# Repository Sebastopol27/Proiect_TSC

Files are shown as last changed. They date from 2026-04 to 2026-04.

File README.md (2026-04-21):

## 1. Diagrama Bloc a Sistemului
Arhitectura hardware este centrata pe microcontrolerul nRF52840, gestionand distributia puterii, comunicatia cu senzorii si interfata vizuala.

      +----------+          +-----------+          +----------+
      |  USB 5V  | -------->|  BQ25180  | -------->|  RT6160  |
      +----------+          | (Charger) |          | (Reg)    |
                            +-----------+          +----------+
                                  ^                     |
                                  |                     | (3.3V Rail)
                                  v                     v
      +----------+          +-----------+          +----------+
      |   LiPo   | <------> |  BAT Node |          | nRF52840 |
      | Battery  |          +-----------+          |  (MCU)   |
      +----------+                |                +----------+
                                  v                     |
                            +-----------+               |
                            | MAX17048  | <-------------+ (I2C Bus)
                            | (Fuel G.) |               |
                            +-----------+               |
                                                        |
         +----------------------------------------------+
         |               |               |              |
         v (I2C)         v (I2C)         v (SPI)        v (GPIO)
   +-----------+   +-----------+   +-----------+   +------------+
   |  BMA421   |   | DRV2605L  |   |  E-Paper  |   | 3x Buttons |
   |  (Accel)  |   | (Haptic)  |   |  Display  |   +------------+
   +-----------+   +-----------+   +-----------+
                         |               ^
                         v               | (Power Gate)
                   +-----------+   +-----------+
                   |Vibe Motor |   | SI2301CDS |
                   +-----------+   |  (PFET)   |
                                   +-----------+

## 2. Bill of Materials (BOM)
Componentele sunt selectate pentru catalogul de asamblare JLCPCB.

| Functie | Componenta | Capsula |
|---|---|---|
| MCU | nRF52840-QIAA  | aQFN73 | 
| Charger | BQ25180YBGR | DSBGA-8 |
| Regulator | RT6160AWSC | WLCSP-15 |
| Fuel Gauge | MAX17048G+T10  | DFN-8 |
| Accel | BMA421 | LGA-12 |
| Haptic Drv | DRV2605LDGSR | VSSOP-10 |
| Vibe Motor | LCM1027B3605F  | Wire |
| EPD PFET | SI2301CDS | SOT-23 |

## 3. Functionalitate Hardware in Detaliu

### Managementul Puterii (Power Tree)
[cite_start]Sistemul utilizeaza o arhitectura tip "power-path":
* **BQ25180**: Gestioneaza incarcarea bateriei LiPo de 250 mAh si asigura tranzitia automata intre alimentarea USB si baterie.
* **RT6160**: Regulator buck-boost setat pentru o iesire de 3.3V (VSEL low), asigurand stabilitatea MCU-ului pe toata durata de descarcare a bateriei.
* **MAX17048**: Monitorizeaza precis tensiunea bateriei si starea de incarcare (SOC) prin masurare directa pe VBAT.

### Senzori si Interfete
* **Magistrala I2C**: Partajata intre accelerometru, fuel gauge, charger, regulator si driverul haptic.
* **Interfata SPI**: Utilizata exclusiv pentru controller-ul ecranului e-paper.
* **BMA421**: Detecteaza pașii mereu activ si trimite intreruperi hardware (INT1) catre MCU pentru wake-up.
* **Haptics**: Driverul DRV2605L controleaza motorul ERM pentru alerte tactile, fiind activat (EN) doar in timpul utilizarii pentru a economisi energie.

### Calcule si Eficienta Consumului
* **Power Gating**: Un PFET (SI2301) controlat de MCU (P1.01) intrerupe alimentarea ecranului e-paper (VEPD) cand acesta nu se afla intr-un ciclu de refresh.
* **Tinta Autonomie**: >= 30 de zile cu refresh de ecran o data pe minut si maxim 50 de notificari zilnice.

## 4. Alocarea Pinilor nRF52840

Pinii au fost selectati pentru a optimiza rutarea pe un PCB cu 4 straturi.

| Componenta | Pin MCU | Justificare / Functie |
|---|---|---|
| **I2C SDA** | P0.06  | Comunicatie date senzori si IC-uri power. |
| **I2C SCL** | P0.07 | Ceas magistrala I2C (10k pull-up extern). |
| **SPI SCK** | P0.02 | Ceas SPI pentru transfer rapid display. |
| **SPI MOSI** | P0.03 | Date seriale catre ecran e-paper. |
| **SPI CS** | P0.05 | Selectie chip afisaj (Chip Select). |
| **EPD DC** | P0.15 | Selectie Data/Command pentru display. |
| **EPD RST** | P0.16 | Reset hardware display. |
| **EPD Busy** | P0.17 | Monitorizare stare procesare refresh ecran. |
| **EPD Power** | P1.01 | Poarta PFET pentru management alimentare VEPD. |
| **Accel INT** | P0.08 | INT1 (wake primar pentru pedometru). |
| **Accel INT2** | P1.08 | INT2 pentru evenimente secundare. |
| **Fuel Gauge** | P0.10 | ALRT pentru prag baterie descarcata. |
| **Charger INT** | P0.11 | Intrerupere pentru evenimente de incarcare. |
| **Haptic EN** | P0.12 | Enable pentru oprirea driverului haptic. |
| **Buttons** | P0.13, P0.14 | Up si Down (active low, wake source). |
| **Button Ent** | P1.00 | Enter / Esc (active low). |

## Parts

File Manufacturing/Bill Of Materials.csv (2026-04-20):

Reference Designators | Quantity | Description | Package | Value | Manufacturer | Manufacturer Part Number | Vendor | Vendor Part Number | Top/Bottom
 | 1 | PCB Board | Board
ANT1 | 1 | Antennas 2.45GHz ANTENNA | 2450AT18B100E_ANTC3216X140N | 2450AT18B100E_2450AT18B100E |  |  |  |  | Top
C1, C2, C17, C18 | 4 | Generic chip capacitor | NORDIC_NRF_3_RESC0201_L | 12p |  |  |  |  | Top
C1-EP-DR, C24, C39 | 3 | 0402 (1005 Metric) | PERFECT_0402_0402 | 10u |  |  |  |  | Top
C2-EP-DR | 1 | Generic chip capacitor | NORDIC_NRF_3_RESC0603_L | 4.7u/25V |  |  |  |  | Top
C3, C4 | 2 | Generic chip capacitor | NORDIC_NRF_3_RESC0201_L | 1p |  |  |  |  | Top
C5, C7, C8, C12, C19 | 5 | Generic chip capacitor | NORDIC_NRF_3_RESC0201_L | 100n |  |  |  |  | Top
C6, C14, C20, C21, C43 | 5 | 0402 (1005 Metric) | PERFECT_0402_0402 | 4.7u |  |  |  |  | Top
C9 | 1 | Generic chip capacitor | NORDIC_NRF_3_RESC0201_L | 820p (N.C.) |  |  |  |  | Top
C10, C22 | 2 | Generic chip capacitor | NORDIC_NRF_3_RESC0201_L | N.C. |  |  |  |  | Top
C11 | 1 | Generic chip capacitor | NORDIC_NRF_3_RESC0201_L | 100p |  |  |  |  | Top
C13 | 1 | 0402 (1005 Metric) | PERFECT_0402_0402 | N.C. |  |  |  |  | Top
C15, C29, C30, C31, C32, C37, C38 | 7 | 0402 (1005 Metric) | PERFECT_0402_0402 | 1u |  |  |  |  | Top
C16 | 1 | Generic chip capacitor | NORDIC_NRF_3_RESC0201_L | 47n |  |  |  |  | Top
C23, C27, C34, C42 | 4 | Generic chip capacitor | NORDIC_NRF_3_RESC0201_L | 0.1u |  |  |  |  | Top
C25 | 1 | Generic chip capacitor | NORDIC_NRF_3_RESC0201_L | 22u |  |  |  |  | Top
C33 | 1 | 0402 (1005 Metric) | PERFECT_0402_0402 | 22u |  |  |  |  | Top
D2, D4, D5 | 3 | ON SEMICONDUCTOR - MBR0530 - DIODE, SCHOTTKY, 0.5A, 30V, SOD-123 | SOD3716X135N | MBR0530 |  |  |  |  | Top
D3\ | 1 | Low Cap. ESD Protection Auto SOT-23-6 STMicroelectronics USBLC6-2SC6Y, Dual Uni-Directional TVS Diode Array, 6-Pin SOT-23 | SOT95P280X145-6N | ESP32_C6_LIBRARY_3_USBLC6-2SC6Y |  |  |  |  | Top
EPD_C1, EPD_C2, EPD_C6, EPD_C7, EPD_C8, EPD_C9, EPD_C10, EPD_C11, EPD_C12 | 9 | Generic chip capacitor | NORDIC_NRF_3_RESC0603_L | 1u/50V |  |  |  |  | Top
EPD_C5 | 1 | Generic chip capacitor | NORDIC_NRF_3_RESC0603_L | 0.1u/50V |  |  |  |  | Top
IC1 | 1 | Charger IC Lithium Ion/Polymer, Lithium Iron Phosphate 8-DSBGA (1.6x1.1) | BQ25180YBGR_BGA8C40P2X4_100X155X50 | BQ25180YBGR_BQ25180YBGR |  |  |  |  | Top
IC2 | 1 | Haptic Driver for ERM/LRA with Built-In Library and Smart Loop Architecture | DRV2605YZFR_BGA9C50P3X3_144X144X62 | DRV2605YZFR |  |  |  |  | Top
IC3 | 1 | Accelerometers Triaxial low-g 12bit Acceleration Sensor | BMA423_BMA423 | BMA423_BMA423 |  |  |  |  | Top
IC9 | 1 | Buck-Boost Regulator Positive Output Step-Up/Step-Down I2C DC-DC Controller IC 15-WL-CSP (BSC) (1.4x2.3) | RT6160AWSC_BGA15C40P3X5_140X230X60 | RT6160AWSC_RT6160AWSC |  |  |  |  | Top
J1 | 1 | FFC & FPC Connectors 0.5mm FPC RA SMT Dual Contact 24Ckt | 503480-2400_5034802400 | 503480-2400_503480-2400 |  |  |  |  | Top
J2 | 1 | CABLE ADAPTER 6 POS | TC2030-IDC_TC2030IDC | TC2030-IDC_TC2030-IDC |  |  |  |  | Top
J4 | 1 | Check availability | KINGHELM_KH-TYPE-C-16P | KH-TYPE-C-16P_KH-TYPE-C-16P |  |  |  |  | Top
L1 | 1 | Generic chip inductor | NORDIC_NRF_2_RESC0201_L | 3.9n |  |  |  |  | Top
L2 | 1 | Generic chip inductor | NORDIC_NRF_2_RESC0402_L | 10u |  |  |  |  | Top
L3 | 1 | Generic chip inductor | NORDIC_NRF_2_RESC0201_L | 15n |  |  |  |  | Top
L5 | 1 |  | ESP32_C6_LIBRARY_2_IND_4828-WE-TPC_WRE | 68u |  |  |  |  | Top
L7 | 1 | SMD / SMT Inductors (Coils), L=0.47?H, L x W x T : | MLP2016SR47MT0S1_INDC2016X100N | FTC252012SR47MBCA |  |  |  |  | Top
Q1 | 1 | P-channel MOSFETs | ESP32_WROVER_SPARKFUN-DISCRETESEMI_SOT23-3 | 20V/4.2A/52mΩ/1.4W |  |  |  |  | Top
Q3 | 1 | MOSFET N-Ch 30V 1.5A TrenchFET SC70 Vishay Si1308EDL-T1-GE3 N-channel MOSFET Transistor, 1.5 A, 30 V, 3-Pin SC-70 | SOT65P210X110-3N | ESP32_C6_LIBRARY_6_SI1308EDL-T1-GE3 |  |  |  |  | Top
R_PWR_EPD, R2_EP_DR, R5, R7, R8 | 5 | 7.68k 0201 Thin Film Surface Mount Fixed Resistor +/-0.5% 0.031W CPF0201D7K68C1 | CPF0201D7K68C1_0201 | 10K |  |  |  |  | Top
R1_EP_DR | 1 | 7.68k 0201 Thin Film Surface Mount Fixed Resistor +/-0.5% 0.031W CPF0201D7K68C1 | CPF0201D7K68C1_0201 | 0.47 |  |  |  |  | Top
R1_TYPE_SEL | 1 | 7.68k 0201 Thin Film Surface Mount Fixed Resistor +/-0.5% 0.031W CPF0201D7K68C1 | CPF0201D7K68C1_0201 | 2.2 |  |  |  |  | Top
R1_USB, R2_USB | 2 | 7.68k 0201 Thin Film Surface Mount Fixed Resistor +/-0.5% 0.031W CPF0201D7K68C1 | CPF0201D7K68C1_0201 | 5K1 |  |  |  |  | Top
R2, R3, R4 | 3 | 7.68k 0201 Thin Film Surface Mount Fixed Resistor +/-0.5% 0.031W CPF0201D7K68C1 | CPF0201D7K68C1_0201 | 0 |  |  |  |  | Top
R9 | 1 | 7.68k 0201 Thin Film Surface Mount Fixed Resistor +/-0.5% 0.031W CPF0201D7K68C1 | CPF0201D7K68C1_0201 | 10k |  |  |  |  | Top
R17, R18 | 2 | 7.68k 0201 Thin Film Surface Mount Fixed Resistor +/-0.5% 0.031W CPF0201D7K68C1 | CPF0201D7K68C1_0201 | 3K3 |  |  |  |  | Top
SJ1 | 1 | SMD solder JUMPER | JUMPER_SJ |  |  |  |  |  | Top
SW_DN, SW_ENT, SW_UP | 3 |  | SW_EVP-AKE31A_PAN | 2025-10-22_07-23-44_LIBRARY_EVP-AKE31ASW_EVP-AKE31A_PAN |  |  |  |  | Top
TP_3.3V, TP_3V3, TP_BAT_GND, TP_GND, TP_ON, TP_OP, TP_RESET, TP_SCL, TP_SDA, TP_SWDCLK, TP_SWDIO, TP_SWO, TP_VBAT, TP_VREG | 14 | Test pad | HECTOR_WATCH_1_TP20R | HECTOR_WATCH_1_TPTP20R |  |  |  |  | Top
U$1 | 1 | nRF52840 | NORDIC_NRF_4_AQFN50P700X700X85_HS-74N | NORDIC_NRF_4_NRF52840_QF |  |  |  |  | Top
U3 | 1 | Check availability | SON50P200X200X80-9N | ESP32_C6_LIBRARY_MAX17048G+T10 |  |  |  |  | Top
X1 | 1 |  | NORDIC_NRF_BT-XTAL_2016_N | 32M |  |  |  |  | Top
X2 | 1 |  | NORDIC_NRF_1_XTAL_3215_N | 32.768k |  |  |  |  | Top

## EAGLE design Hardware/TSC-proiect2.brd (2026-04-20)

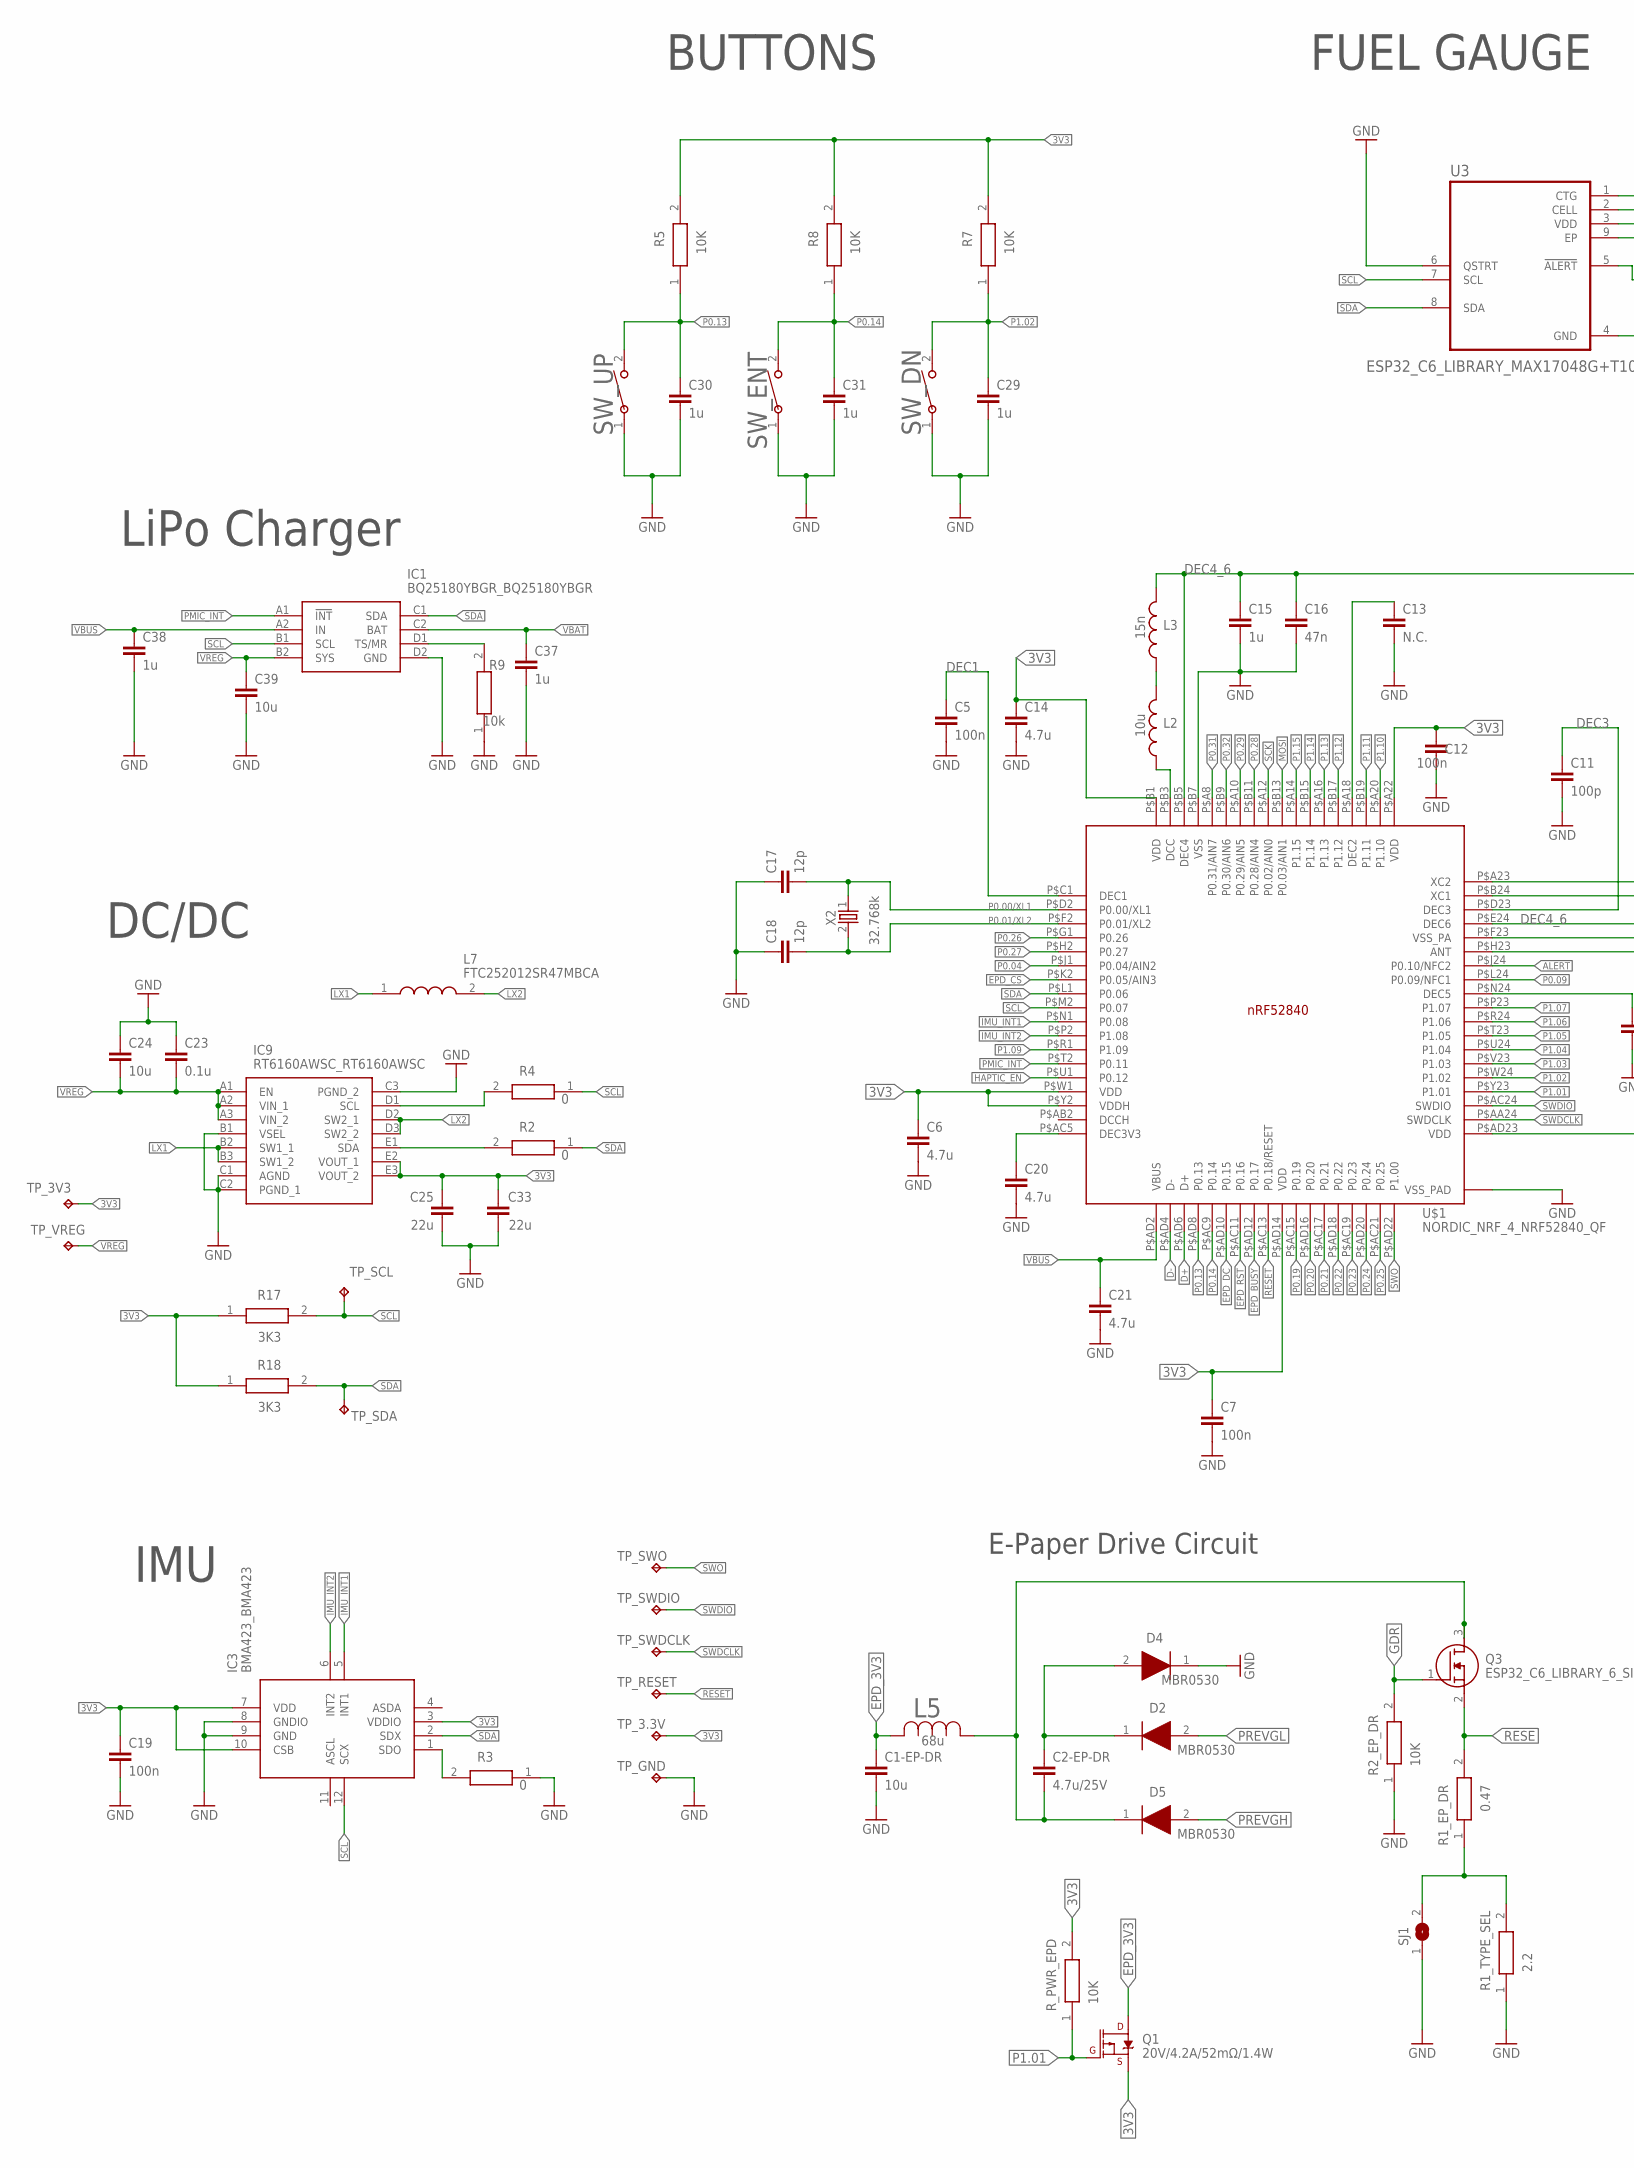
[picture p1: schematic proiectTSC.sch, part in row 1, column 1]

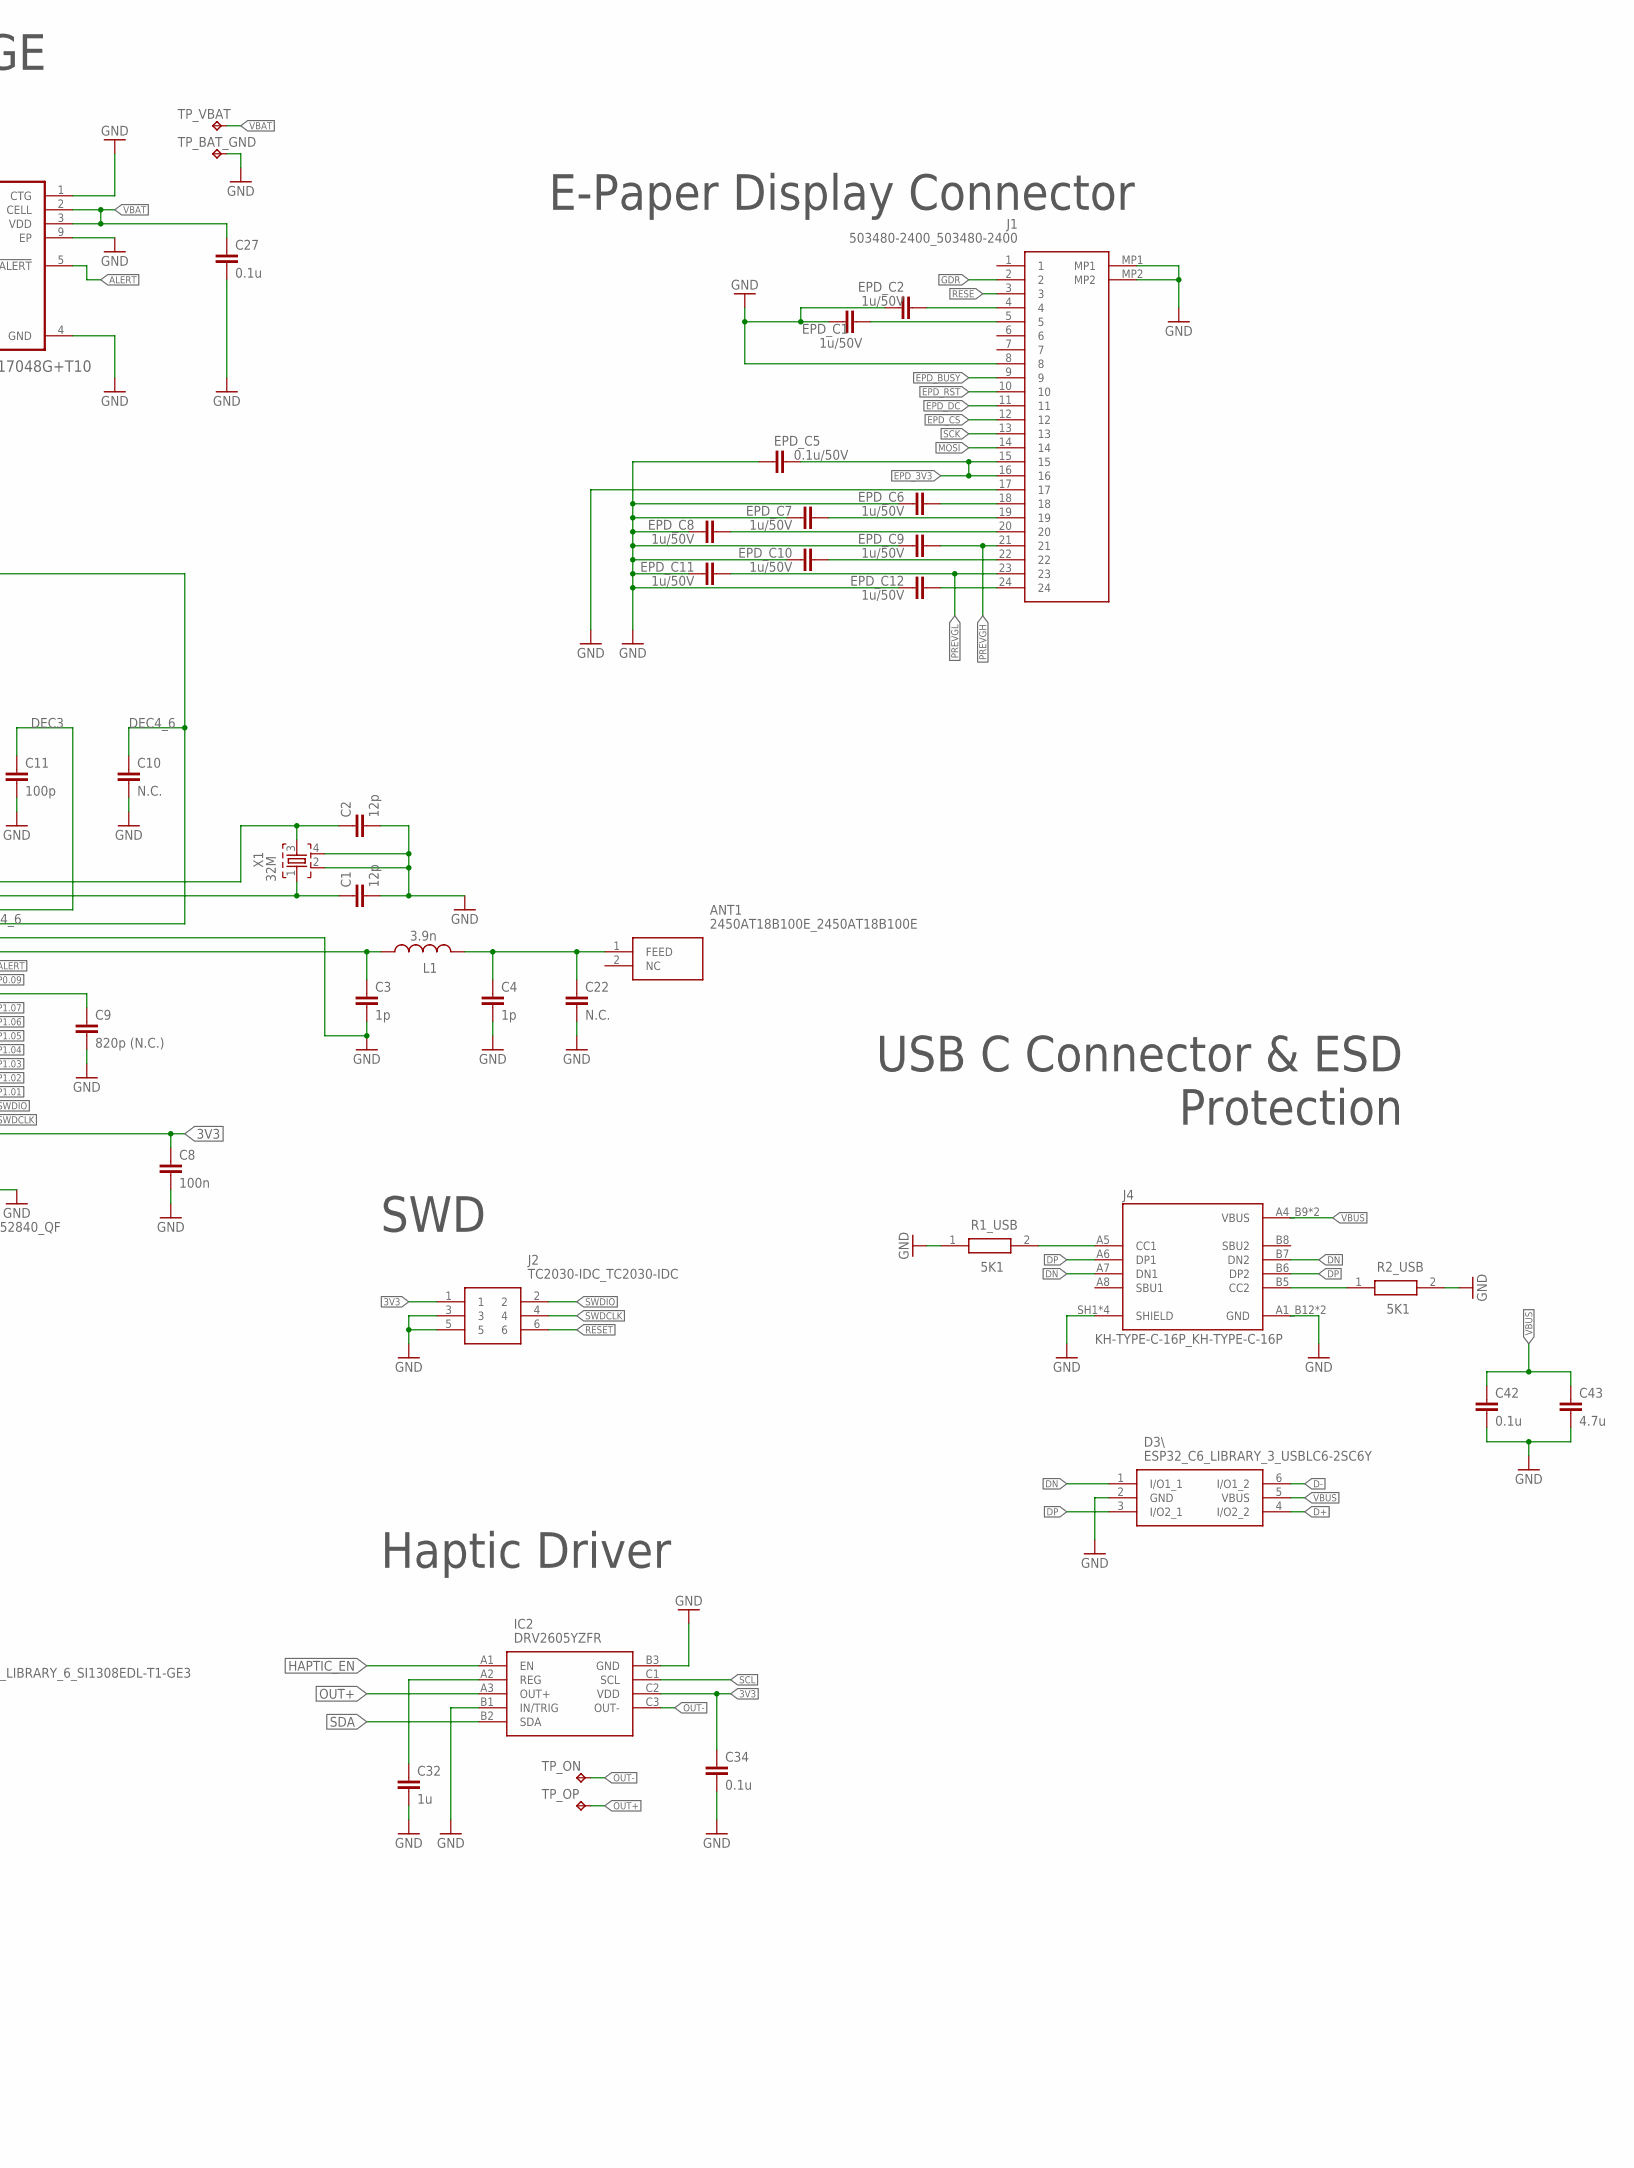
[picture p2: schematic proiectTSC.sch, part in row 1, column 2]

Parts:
ANT1: 2450AT18B100E_2450AT18B100E; 2450AT18B100E_ANTC3216X140N
C1, C2, C17, C18: 12p; NORDIC_NRF_3_RESC0201_L
C1-EP-DR, C24, C39: 10u; PERFECT_0402_0402
C2-EP-DR: 4.7u/25V; NORDIC_NRF_3_RESC0603_L
C3, C4: 1p; NORDIC_NRF_3_RESC0201_L
C5, C7, C8, C12, C19: 100n; NORDIC_NRF_3_RESC0201_L
C6, C14, C20, C21, C43: 4.7u; PERFECT_0402_0402
C9: 820p (N.C.); NORDIC_NRF_3_RESC0201_L
C10, C22: N.C.; NORDIC_NRF_3_RESC0201_L
C11: 100p; NORDIC_NRF_3_RESC0201_L
C13: N.C.; PERFECT_0402_0402
C15, C29, C30, C31, C32, C37, C38: 1u; PERFECT_0402_0402
C16: 47n; NORDIC_NRF_3_RESC0201_L
C23, C27, C34, C42: 0.1u; NORDIC_NRF_3_RESC0201_L
C25: 22u; NORDIC_NRF_3_RESC0201_L
C33: 22u; PERFECT_0402_0402
D2, D4, D5: MBR0530; ESP32_C6_LIBRARY_5_SOD3716X135N
D3\: ESP32_C6_LIBRARY_3_USBLC6-2SC6Y; ESP32_C6_LIBRARY_3_SOT95P280X145-6N
EPD_C1, EPD_C2, EPD_C6, EPD_C7, EPD_C8, EPD_C9, EPD_C10, EPD_C11, EPD_C12: 1u/50V; NORDIC_NRF_3_RESC0603_L
EPD_C5: 0.1u/50V; NORDIC_NRF_3_RESC0603_L
IC1: BQ25180YBGR_BQ25180YBGR; BQ25180YBGR_BGA8C40P2X4_100X155X50
IC2: DRV2605YZFR; DRV2605YZFR_BGA9C50P3X3_144X144X62
IC3: BMA423_BMA423
IC9: RT6160AWSC_RT6160AWSC; RT6160AWSC_BGA15C40P3X5_140X230X60
J1: 503480-2400_503480-2400; 503480-2400_5034802400
J2: TC2030-IDC_TC2030-IDC; TC2030-IDC_TC2030IDC
J4: KH-TYPE-C-16P_KH-TYPE-C-16P; KH-TYPE-C-16P_KINGHELM_KH-TYPE-C-16P
L1: 3.9n; NORDIC_NRF_2_RESC0201_L
L2: 10u; NORDIC_NRF_2_RESC0402_L
L3: 15n; NORDIC_NRF_2_RESC0201_L
L5: 68u; ESP32_C6_LIBRARY_2_IND_4828-WE-TPC_WRE
L7: FTC252012SR47MBCA; MLP2016SR47MT0S1_INDC2016X100N
Q1: 20V/4.2A/52mΩ/1.4W; ESP32_C6_LIBRARY_4_ESP32_C6_LIBRARY_4_ESP32_C6_LIBRARY_4_ES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
Q3: ESP32_C6_LIBRARY_6_SI1308EDL-T1-GE3; ESP32_C6_LIBRARY_6_SOT65P210X110-3N
R1_EP_DR: 0.47; CPF0201D7K68C1_0201
R1_TYPE_SEL: 2.2; CPF0201D7K68C1_0201
R1_USB, R2_USB: 5K1; CPF0201D7K68C1_0201
R2, R3, R4: 0; CPF0201D7K68C1_0201
R2_EP_DR, R5, R7, R8: 10K; CPF0201D7K68C1_0201
R9: 10k; CPF0201D7K68C1_0201
R17, R18: 3K3; CPF0201D7K68C1_0201
R_PWR_EPD: 10K; CPF0201D7K68C1_0201
SJ1: ESP32_C6_LIBRARY_7_JUMPER_SJ
SW_DN: 2025-10-22_07-23-44_LIBRARY_EVP-AKE31ASW_EVP-AKE3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; 2025-10-22_07-23-44_LIBRARY_SW_EVP-AKE31A_PAN
SW_ENT: 2025-10-22_07-23-44_LIBRARY_EVP-AKE31ASW_EVP-AKE3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; 2025-10-22_07-23-44_LIBRARY_SW_EVP-AKE31A_PAN
SW_UP: 2025-10-22_07-23-44_LIBRARY_EVP-AKE31ASW_EVP-AKE3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; 2025-10-22_07-23-44_LIBRARY_SW_EVP-AKE31A_PAN
TP_3.3V, TP_3V3: HECTOR_WATCH_1_TPTP20R; HECTOR_WATCH_1_TP20R
TP_BAT_GND: HECTOR_WATCH_1_TPTP20R; HECTOR_WATCH_1_TP20R
TP_GND: HECTOR_WATCH_1_TPTP20R; HECTOR_WATCH_1_TP20R
TP_ON: HECTOR_WATCH_1_TPTP20R; HECTOR_WATCH_1_TP20R
TP_OP: HECTOR_WATCH_1_TPTP20R; HECTOR_WATCH_1_TP20R
TP_RESET: HECTOR_WATCH_1_TPTP20R; HECTOR_WATCH_1_TP20R
TP_SCL: HECTOR_WATCH_1_TPTP20R; HECTOR_WATCH_1_TP20R
TP_SDA: HECTOR_WATCH_1_TPTP20R; HECTOR_WATCH_1_TP20R
TP_SWDCLK: HECTOR_WATCH_1_TPTP20R; HECTOR_WATCH_1_TP20R
TP_SWDIO: HECTOR_WATCH_1_TPTP20R; HECTOR_WATCH_1_TP20R
TP_SWO: HECTOR_WATCH_1_TPTP20R; HECTOR_WATCH_1_TP20R
TP_VBAT: HECTOR_WATCH_1_TPTP20R; HECTOR_WATCH_1_TP20R
TP_VREG: HECTOR_WATCH_1_TPTP20R; HECTOR_WATCH_1_TP20R
U3: ESP32_C6_LIBRARY_MAX17048G+T10; ESP32_C6_LIBRARY_SON50P200X200X80-9N
U$1: NORDIC_NRF_4_NRF52840_QF; NORDIC_NRF_4_AQFN50P700X700X85_HS-74N
X1: 32M; NORDIC_NRF_BT-XTAL_2016_N
X2: 32.768k; NORDIC_NRF_1_XTAL_3215_N

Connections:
3V3: C6.1, C7.1, C8.1, C12.1, C14.1, C19.1, C25.2, C33.2, C34.1, IC2.C2 (VDD), IC3.3 (VDDIO), IC3.7 (VDD), IC3.10 (CSB), IC9.E2 (VOUT_1), IC9.E3 (VOUT_2), J2.1, Q1.2 (S), R5.2, R7.2, R8.2, R_PWR_EPD.2, TP_3.3V.TP, TP_3V3.TP, U$1.P$A22 (VDD), U$1.P$AD14 (VDD), U$1.P$AD23 (VDD), U$1.P$B1 (VDD), U$1.P$W1 (VDD), U$1.P$Y2 (VDDH)
ALERT: U3.5 (!ALERT), U$1.P$J24 (P0.10/NFC2)
D+: D3\.4 (I/O2_2), U$1.P$AD6 (D+)
D-: D3\.6 (I/O1_2), U$1.P$AD4 (D-)
DEC1: C5.1, U$1.P$C1 (DEC1)
DEC3: C11.1, U$1.P$D23 (DEC3)
DEC4_6: C10.1, C15.1, C16.1, L3.2, U$1.P$B5 (DEC4), U$1.P$E24 (DEC6)
DN: D3\.1 (I/O1_1), J4.A7 (DN1), J4.B7 (DN2)
DP: D3\.3 (I/O2_1), J4.A6 (DP1), J4.B6 (DP2)
EPD_3V3: C1-EP-DR.1, EPD_C5.2, J1.15, J1.16, L5.2, Q1.3 (D)
EPD_BUSY: J1.9, U$1.P$AD12 (P0.17)
EPD_CS: J1.12, U$1.P$K2 (P0.05/AIN3)
EPD_DC: J1.11, U$1.P$AD10 (P0.15)
EPD_RST: J1.10, U$1.P$AC11 (P0.16)
GDR: J1.2, Q3.1 (G), R2_EP_DR.2
GND: C1.2, C1-EP-DR.2, C2.2, C3.2, C4.2, C5.2, C6.2, C7.2, C8.2, C9.2, C10.2, C11.2, C12.2, C13.2, C14.2, C15.2, C16.2, C17.1, C18.1, C19.2, C20.2, C21.2, C22.2, C23.1, C24.1, C25.1, C27.2, C29.2, C30.2, C31.2, C32.2, C33.1, C34.2, C37.2, C38.2, C39.2, C42.2, C43.2, D3\.2 (GND), D4.1 (K), EPD_C1.1, EPD_C2.1, EPD_C5.1, EPD_C6.1, EPD_C7.1, EPD_C8.1, EPD_C9.1, EPD_C10.1, EPD_C11.1, EPD_C12.1, IC1.D2 (GND), IC2.B1 (IN/TRIG), IC2.B3 (GND), IC3.8 (GNDIO), IC3.9 (GND), IC9.B1 (VSEL), IC9.C1 (AGND), IC9.C2 (PGND_1), IC9.C3 (PGND_2), J1.8, J1.17, J1.MP1, J1.MP2, J2.3, J2.5, J4.A1_B12 (GND), J4.A12_B1 (GND), J4.SH1 (SHIELD), J4.SH2 (SHIELD), J4.SH3 (SHIELD), J4.SH4 (SHIELD), R1_TYPE_SEL.1, R1_USB.1, R2_EP_DR.1, R2_USB.2, R3.1, R9.1, SJ1.1, SW_DN.1, SW_ENT.1, SW_UP.1, TP_BAT_GND.TP, TP_GND.TP, U3.1 (CTG), U3.4 (GND), U3.6 (QSTRT), U3.9 (EP), U$1.P$74 (VSS_PAD), U$1.P$75 (VSS_PAD), U$1.P$76 (VSS_PAD), U$1.P$77 (VSS_PAD), U$1.P$78 (VSS_PAD), U$1.P$79 (VSS_PAD), U$1.P$80 (VSS_PAD), U$1.P$81 (VSS_PAD), U$1.P$82 (VSS_PAD), U$1.P$83 (VSS_PAD), U$1.P$84 (VSS_PAD), U$1.P$85 (VSS_PAD), U$1.P$86 (VSS_PAD), U$1.P$87 (VSS_PAD), U$1.P$88 (VSS_PAD), U$1.P$89 (VSS_PAD), U$1.P$90 (VSS_PAD), U$1.P$B7 (VSS), U$1.P$F23 (VSS_PA), X1.2, X1.4
HAPTIC_EN: IC2.A1 (EN), U$1.P$U1 (P0.12)
IMU_INT1: IC3.5 (INT1), U$1.P$N1 (P0.08)
IMU_INT2: IC3.6 (INT2), U$1.P$P2 (P1.08)
LX1: IC9.B2 (SW1_1), IC9.B3 (SW1_2), L7.1
LX2: IC9.D2 (SW2_1), IC9.D3 (SW2_2), L7.2
MOSI: J1.14, U$1.P$B13 (P0.03/AIN1)
unnamed: L2.1, U$1.P$B3 (DCC)
unnamed: L2.2, L3.1
unnamed: C13.1, U$1.P$A18 (DEC2)
unnamed: C20.1, U$1.P$AC5 (DEC3V3)
unnamed: C9.1, U$1.P$N24 (DEC5)
unnamed: C3.1, L1.1, U$1.P$H23 (ANT)
unnamed: ANT1.1 (FEED), C4.1, C22.1, L1.2
unnamed: C1.1, U$1.P$B24 (XC1), X1.1
unnamed: C2.1, U$1.P$A23 (XC2), X1.3
unnamed: IC1.D1 (TS/MR), R9.2
unnamed: IC9.D1 (SCL), R4.2
unnamed: IC9.E1 (SDA), R2.2
unnamed: R17.1, R18.1
unnamed: R1_EP_DR.1, R1_TYPE_SEL.2, SJ1.2
unnamed: C32.1, IC2.A2 (REG)
unnamed: C2-EP-DR.1, D2.1 (K), D4.2 (A)
unnamed: C2-EP-DR.2, D5.1 (K), L5.1, Q3.3 (D)
unnamed: IC3.1 (SDO), R3.2
unnamed: EPD_C6.2, J1.18
unnamed: EPD_C7.2, J1.19
unnamed: EPD_C2.2, J1.4
unnamed: EPD_C1.2, J1.5
unnamed: EPD_C8.2, J1.20
unnamed: EPD_C10.2, J1.22
unnamed: EPD_C12.2, J1.24
unnamed: J4.B5 (CC2), R2_USB.1
unnamed: J4.A5 (CC1), R1_USB.2
OUT+: IC2.A3 (OUT+), TP_OP.TP
OUT-: IC2.C3 (OUT-), TP_ON.TP
P0.00/XL1: C17.2, U$1.P$D2 (P0.00/XL1), X2.1
P0.01/XL2: C18.2, U$1.P$F2 (P0.01/XL2), X2.2
P0.04: U$1.P$J1 (P0.04/AIN2)
P0.09: U$1.P$L24 (P0.09/NFC1)
P0.13: C30.1, R5.1, SW_UP.2, U$1.P$AD8 (P0.13)
P0.14: C31.1, R8.1, SW_ENT.2, U$1.P$AC9 (P0.14)
P0.19: U$1.P$AC15 (P0.19)
P0.20: U$1.P$AD16 (P0.20)
P0.21: U$1.P$AC17 (P0.21)
P0.22: U$1.P$AD18 (P0.22)
P0.23: U$1.P$AC19 (P0.23)
P0.24: U$1.P$AD20 (P0.24)
P0.25: U$1.P$AC21 (P0.25)
P0.26: U$1.P$G1 (P0.26)
P0.27: U$1.P$H2 (P0.27)
P0.28: U$1.P$B11 (P0.28/AIN4)
P0.29: U$1.P$A10 (P0.29/AIN5)
P0.31: U$1.P$A8 (P0.31/AIN7)
P0.32: U$1.P$B9 (P0.30/AIN6)
P1.01: Q1.1 (G), R_PWR_EPD.1, U$1.P$Y23 (P1.01)
P1.02: C29.1, R7.1, SW_DN.2, U$1.P$W24 (P1.02)
P1.03: U$1.P$V23 (P1.03)
P1.04: U$1.P$U24 (P1.04)
P1.05: U$1.P$T23 (P1.05)
P1.06: U$1.P$R24 (P1.06)
P1.07: U$1.P$P23 (P1.07)
P1.09: U$1.P$R1 (P1.09)
P1.10: U$1.P$A20 (P1.10)
P1.11: U$1.P$B19 (P1.11)
P1.12: U$1.P$B17 (P1.12)
P1.13: U$1.P$A16 (P1.13)
P1.14: U$1.P$B15 (P1.14)
P1.15: U$1.P$A14 (P1.15)
PMIC_INT: IC1.A1 (!INT), U$1.P$T2 (P0.11)
PREVGH: D5.2 (A), EPD_C9.2, J1.21
PREVGL: D2.2 (A), EPD_C11.2, J1.23
RESE: J1.3, Q3.2 (S), R1_EP_DR.2
RESET: J2.6, TP_RESET.TP, U$1.P$AC13 (P0.18/RESET)
SCK: J1.13, U$1.P$A12 (P0.02/AIN0)
SCL: IC1.B1 (SCL), IC2.C1 (SCL), IC3.12 (SCX), R4.1, R17.2, TP_SCL.TP, U3.7 (SCL), U$1.P$M2 (P0.07)
SDA: IC1.C1 (SDA), IC2.B2 (SDA), IC3.2 (SDX), R2.1, R18.2, TP_SDA.TP, U3.8 (SDA), U$1.P$L1 (P0.06)
SWDCLK: J2.4, TP_SWDCLK.TP, U$1.P$AA24 (SWDCLK)
SWDIO: J2.2, TP_SWDIO.TP, U$1.P$AC24 (SWDIO)
SWO: TP_SWO.TP, U$1.P$AD22 (P1.00)
VBAT: C27.1, C37.1, IC1.C2 (BAT), TP_VBAT.TP, U3.2 (CELL), U3.3 (VDD)
VBUS: C21.1, C38.1, C42.1, C43.1, D3\.5 (VBUS), IC1.A2 (IN), J4.A4_B9 (VBUS), J4.A9_B4 (VBUS), U$1.P$AD2 (VBUS)
VREG: C23.2, C24.2, C39.1, IC1.B2 (SYS), IC9.A1 (EN), IC9.A2 (VIN_1), IC9.A3 (VIN_2), TP_VREG.TP

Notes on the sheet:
LiPo Charger
DC/DC
IMU
SWD
E-Paper Drive Circuit
Haptic Driver
BUTTONS
FUEL GAUGE
E-Paper Display Connector
USB C Connector & ESD Protection

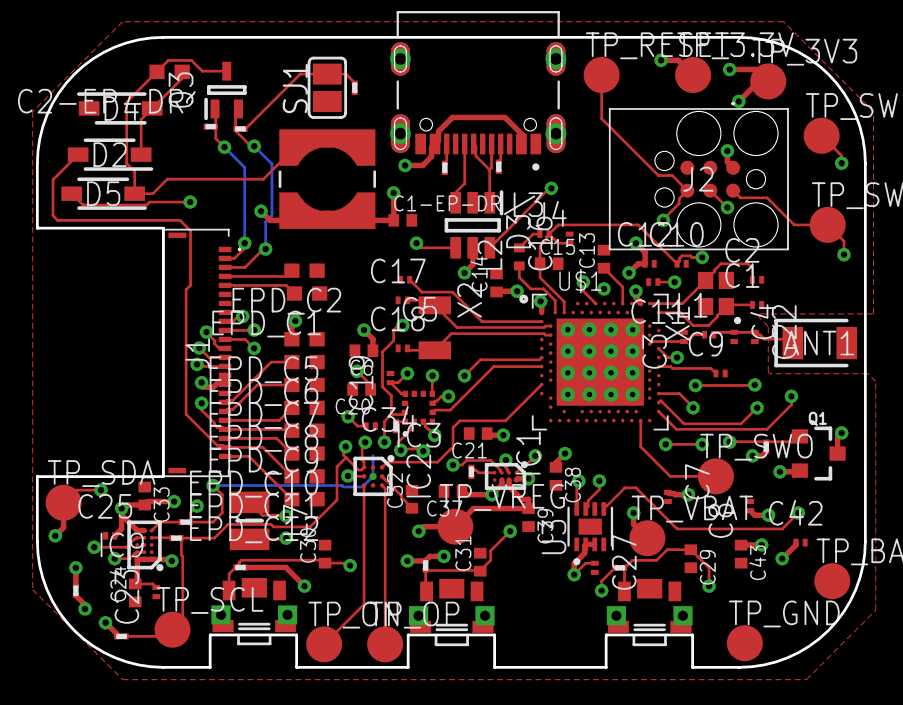
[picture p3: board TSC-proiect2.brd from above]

Board: 4 copper layers, 46.0 x 35.0 mm, 105 parts (0 on the bottom side), 71 nets.

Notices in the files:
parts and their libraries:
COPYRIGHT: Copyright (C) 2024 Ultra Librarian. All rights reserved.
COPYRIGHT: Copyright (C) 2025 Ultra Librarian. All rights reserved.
